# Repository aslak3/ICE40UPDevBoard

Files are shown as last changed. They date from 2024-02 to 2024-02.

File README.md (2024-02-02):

# ICE40UPDevBoard: an iCE40UP5K development board

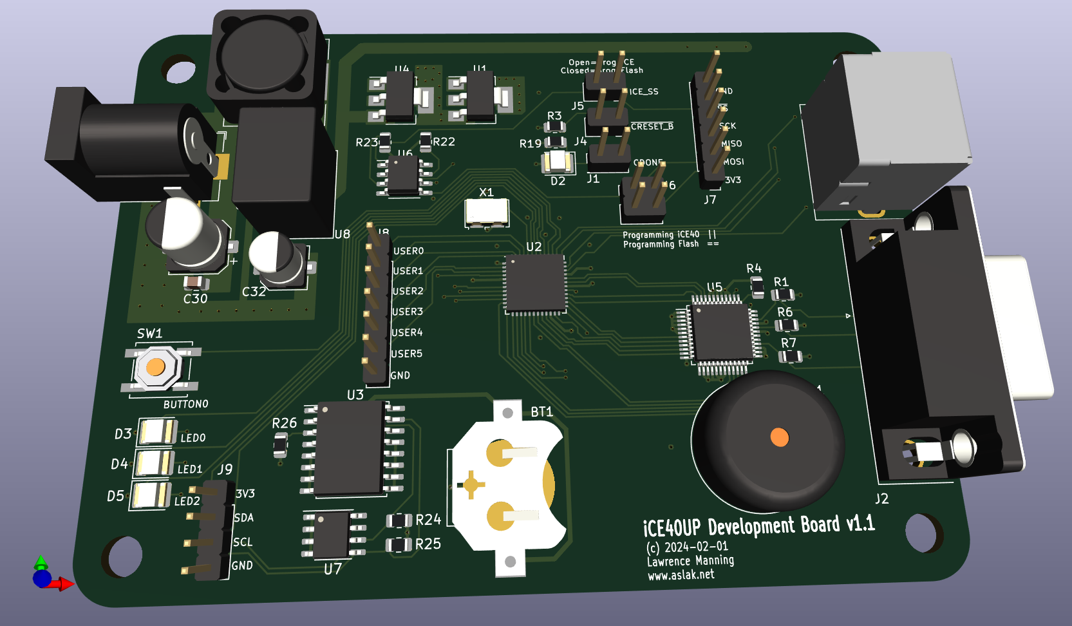
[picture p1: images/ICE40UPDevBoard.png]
ICE40UPDevBoard PCB


## Features

The specification for this development board is as follows:

* [iCE40UP5K](https://www.latticesemi.com/view_document?document_id=51968) in QFN
* [N25Q032A](https://docs.rs-online.com/0866/0900766b80f7f8ab.pdf) 32 Mbit SPI flash
* DB15 VGA port:
  * [ADV7123](https://www.analog.com/media/en/technical-documentation/data-sheets/ADV7123-EP.pdf) RGB DAC
* PS/2 port with two channels for a mouse and keyboard
* I2C:
  * [DS3231M](https://www.analog.com/media/en/technical-documentation/data-sheets/ds3231m.pdf) RTC
  * [AT24C64](https://ww1.microchip.com/downloads/en/devicedoc/doc0336.pdf) EEPROM
  * Header for I2C connections
* 3 LEDs and a button
* User header with 6 available FPGA pins
* Powered by a 5V switching regulator (eg a 5V [PM05S050A](https://filecenter.deltaww.com/products/download/01/0102/datasheet/DS_PM05S.pdf)) and a barrel jack

A [schematic](ICE40UPDevBoard.pdf) is included here, along with the
[KiCAD](https://www.kicad.org) data files, whcih are in  KiCAD 6 format.

## PCB design

The PCB is a 4 layer board.  My boards were manufactured by
[JLCPCB](https://www.jlcpcb.com).

## Using

The jumper mechanism to route the SPI signals which carry the configuration
data from the programmer was borrowed directly from the [Lattice’s iCE40
UltraPlus Breakout
Board](https://www.latticesemi.com/view_document?document_id=51987).

Any iCE40 compatible programmer should be useable.  I built my own, out of a
Pi Pico, which is documented in [another repo](https://github.com/aslak3/spi-flasher).
The programmer has been used to program both the attached flash and the FPGA directly.

## Possible gotchas

The design of this board is a very slightly tweaked version of the build I
have on my bench.  I have tweaked the LED and button connection after
finding out that the three LED pins on the iCE40UP cannot source current for
an LED and must sink it instead.

The following features have not been tested yet:

* I2C bus and peripheral ICs
* PS/2 port

## Blog

The best place to learn about this board is undoubtably [my
blog](https://www.aslak.net/), including this post:

* [Design and build of a Lattice iCE40UP development board](https://www.aslak.net/index.php/2024/01/31/design-and-build-of-a-lattice-ice40up-development-board/)

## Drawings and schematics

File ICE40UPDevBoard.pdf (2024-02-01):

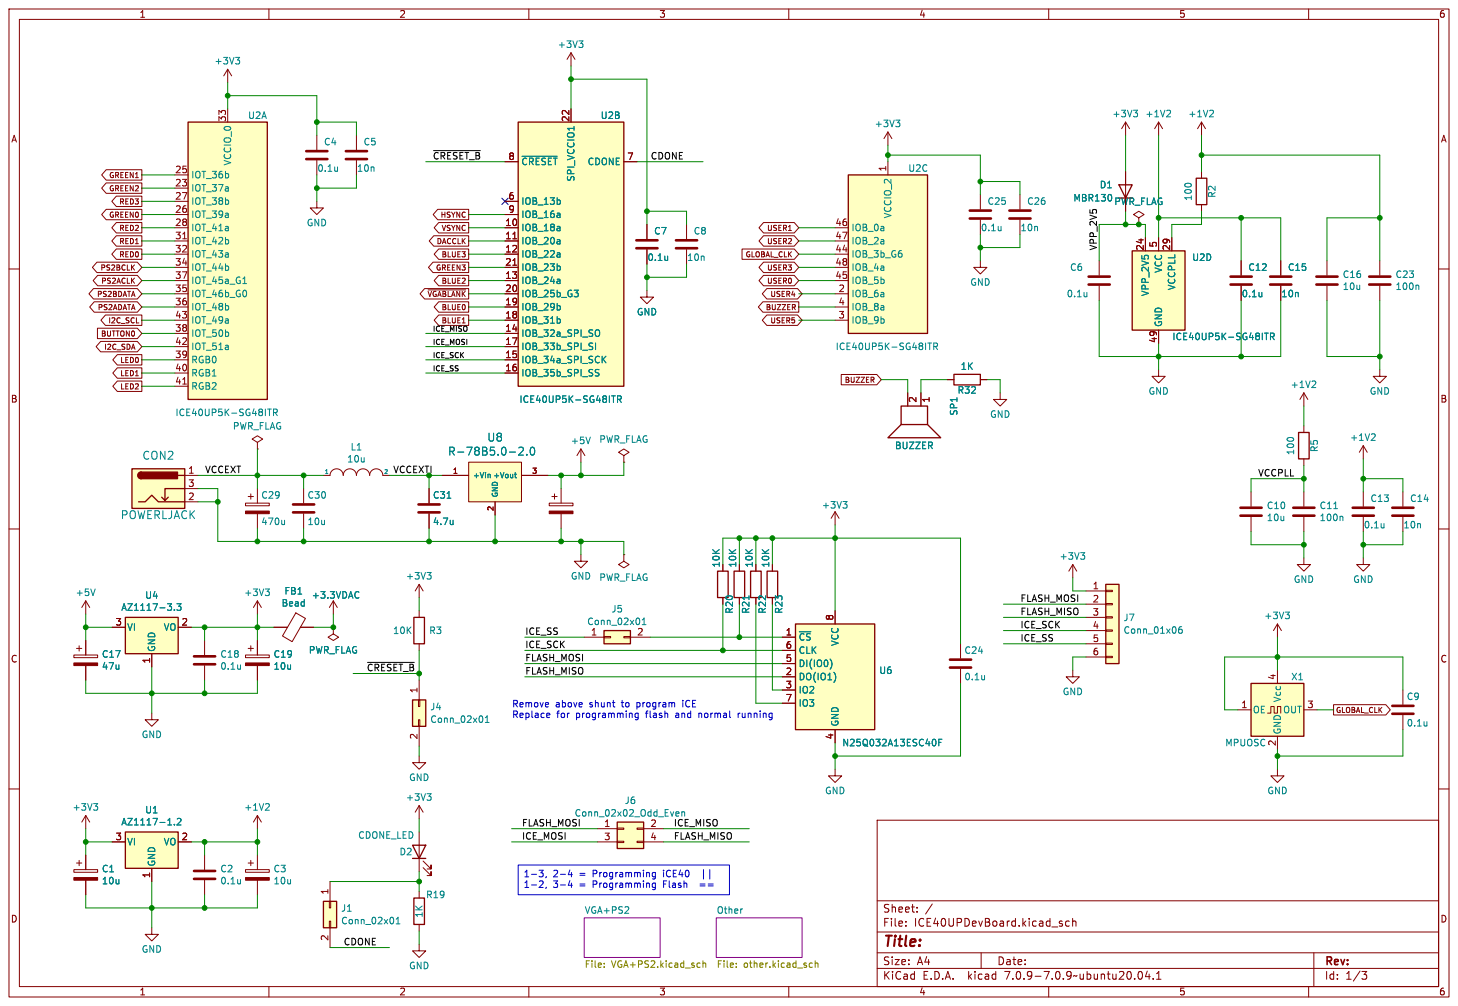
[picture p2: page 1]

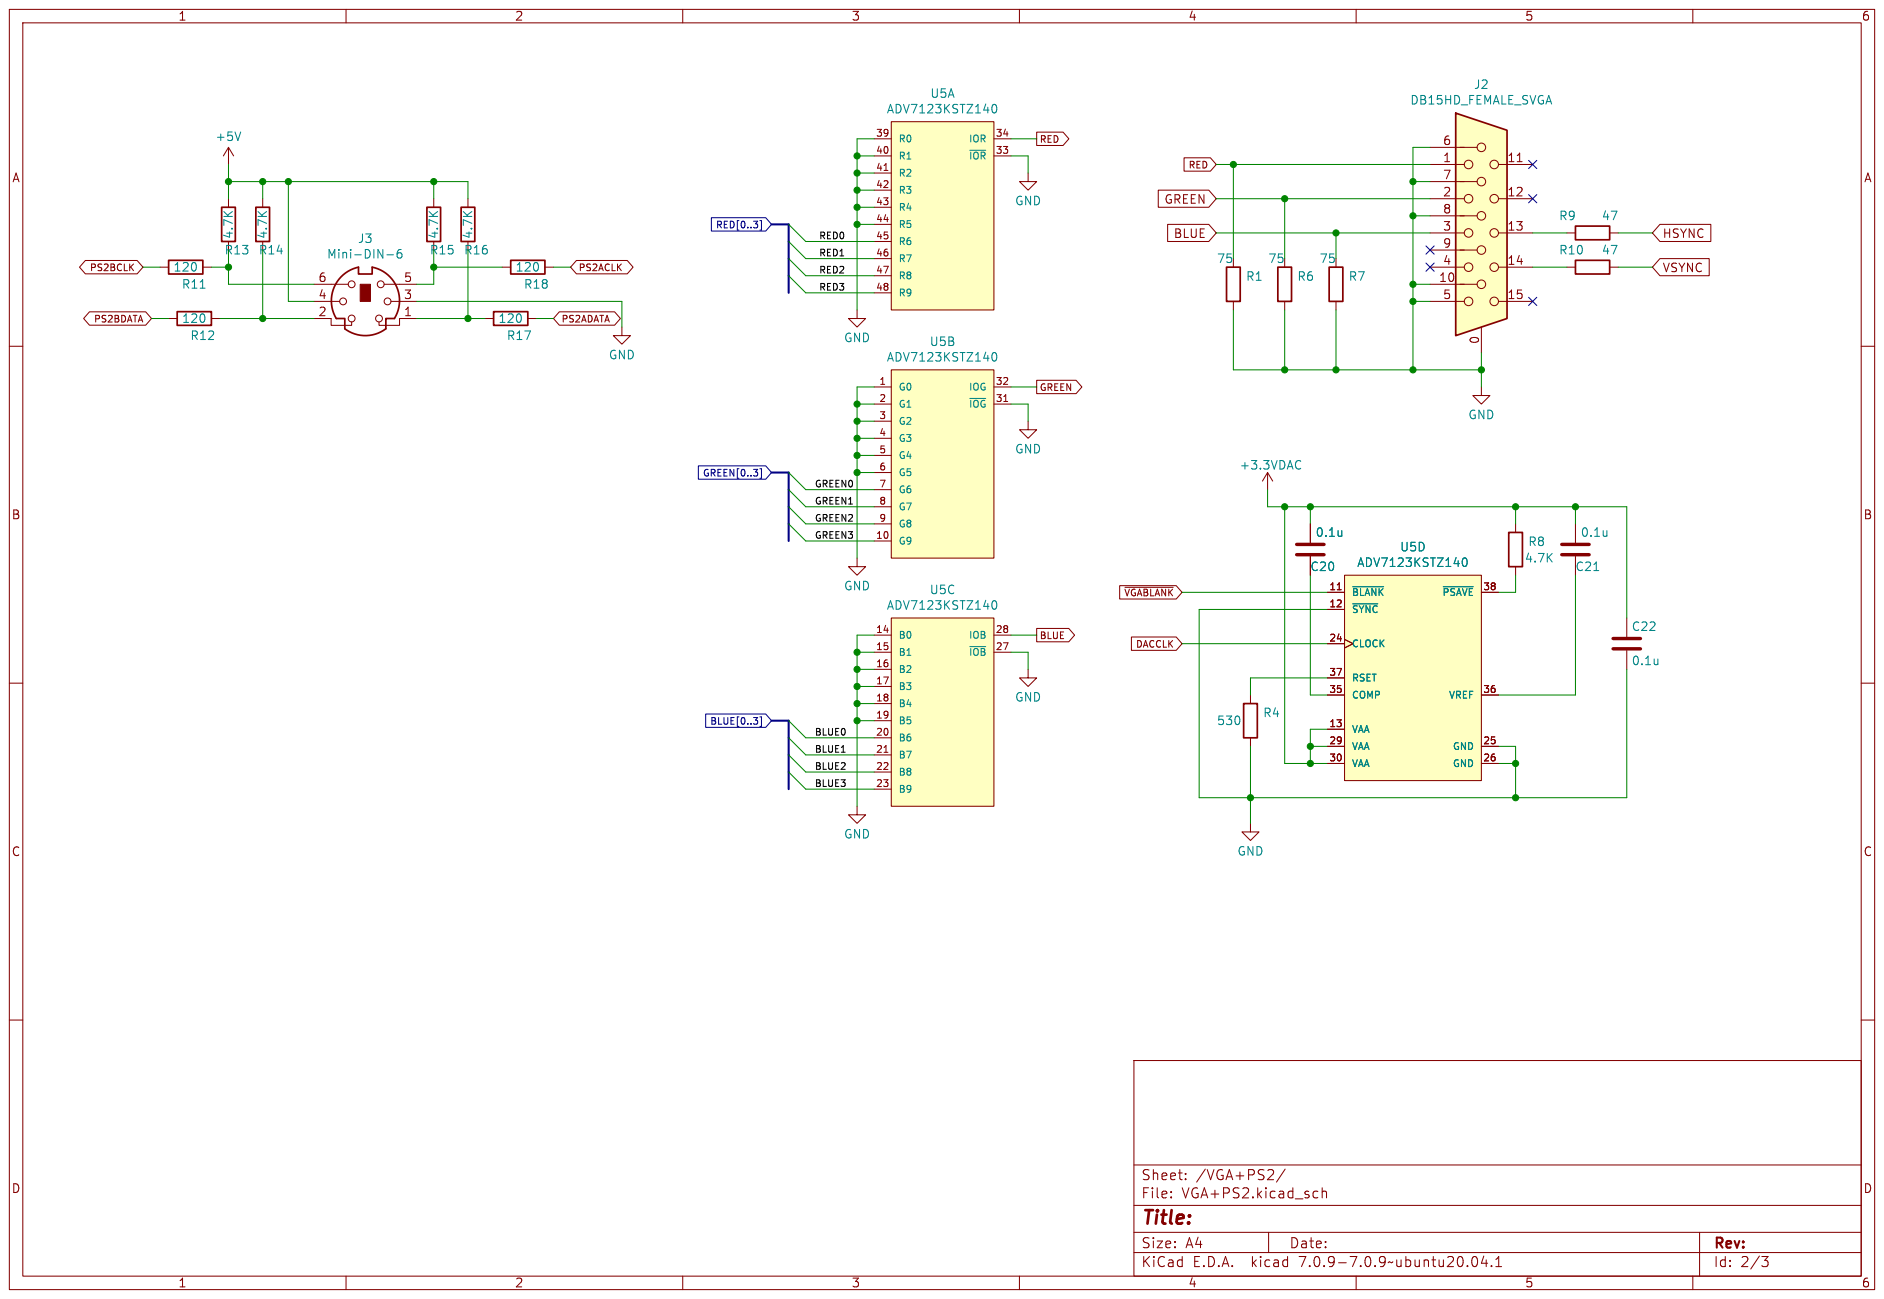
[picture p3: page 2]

Id: 2/3 Title: File: VGA+PS2.kicad_sch Sheet: /VGA+PS2/

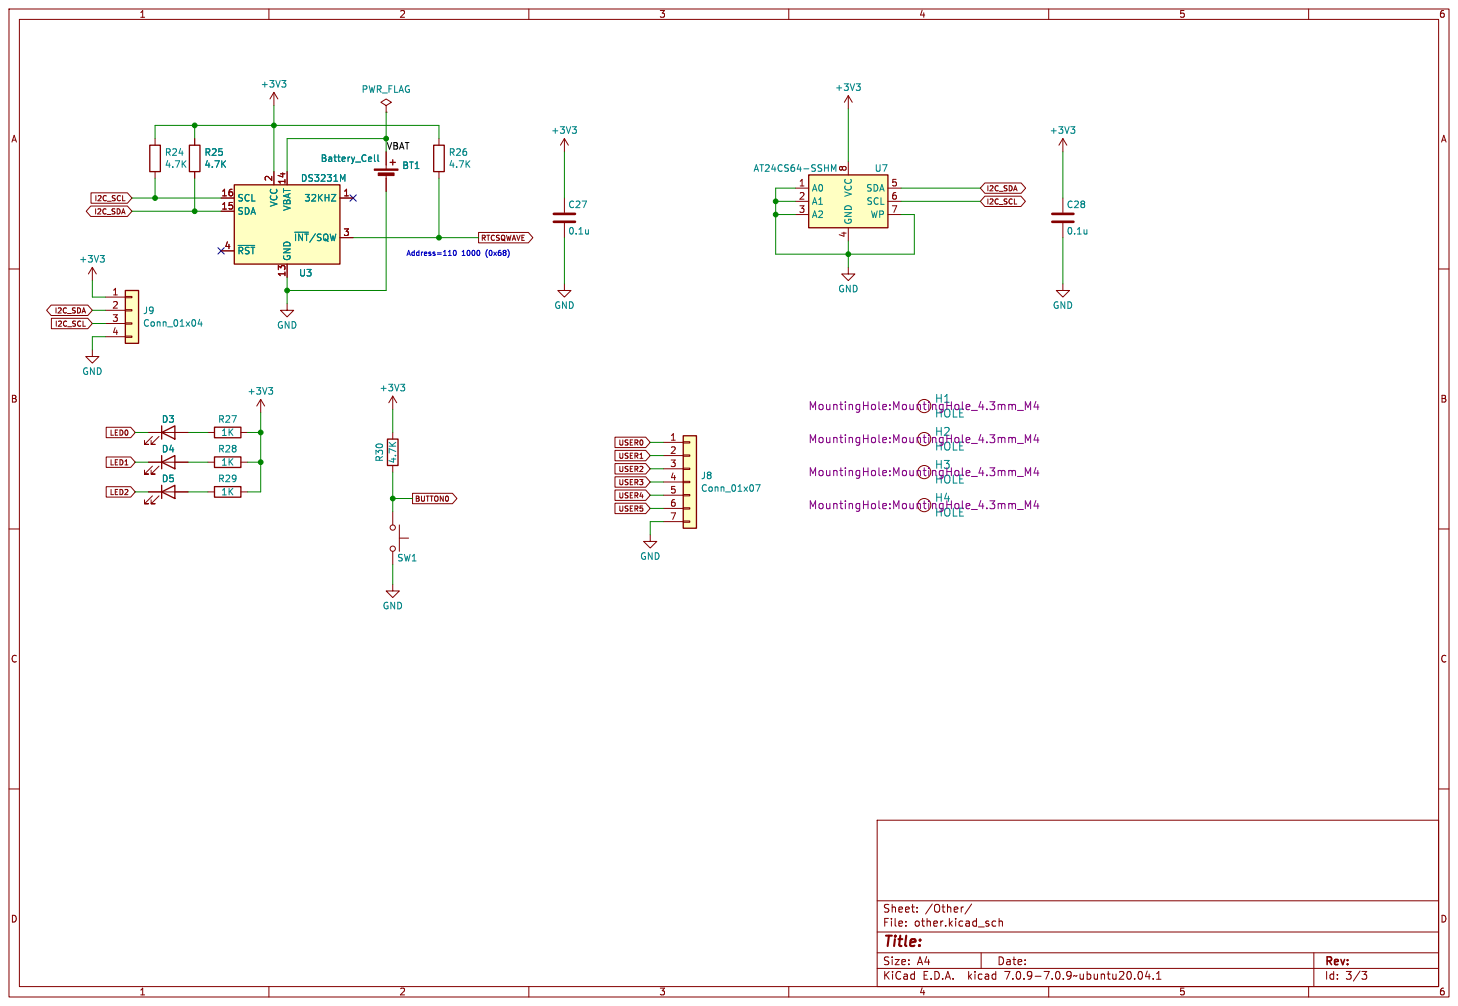
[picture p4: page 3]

4 SDA 5 SCL 6 WP 7 VCC

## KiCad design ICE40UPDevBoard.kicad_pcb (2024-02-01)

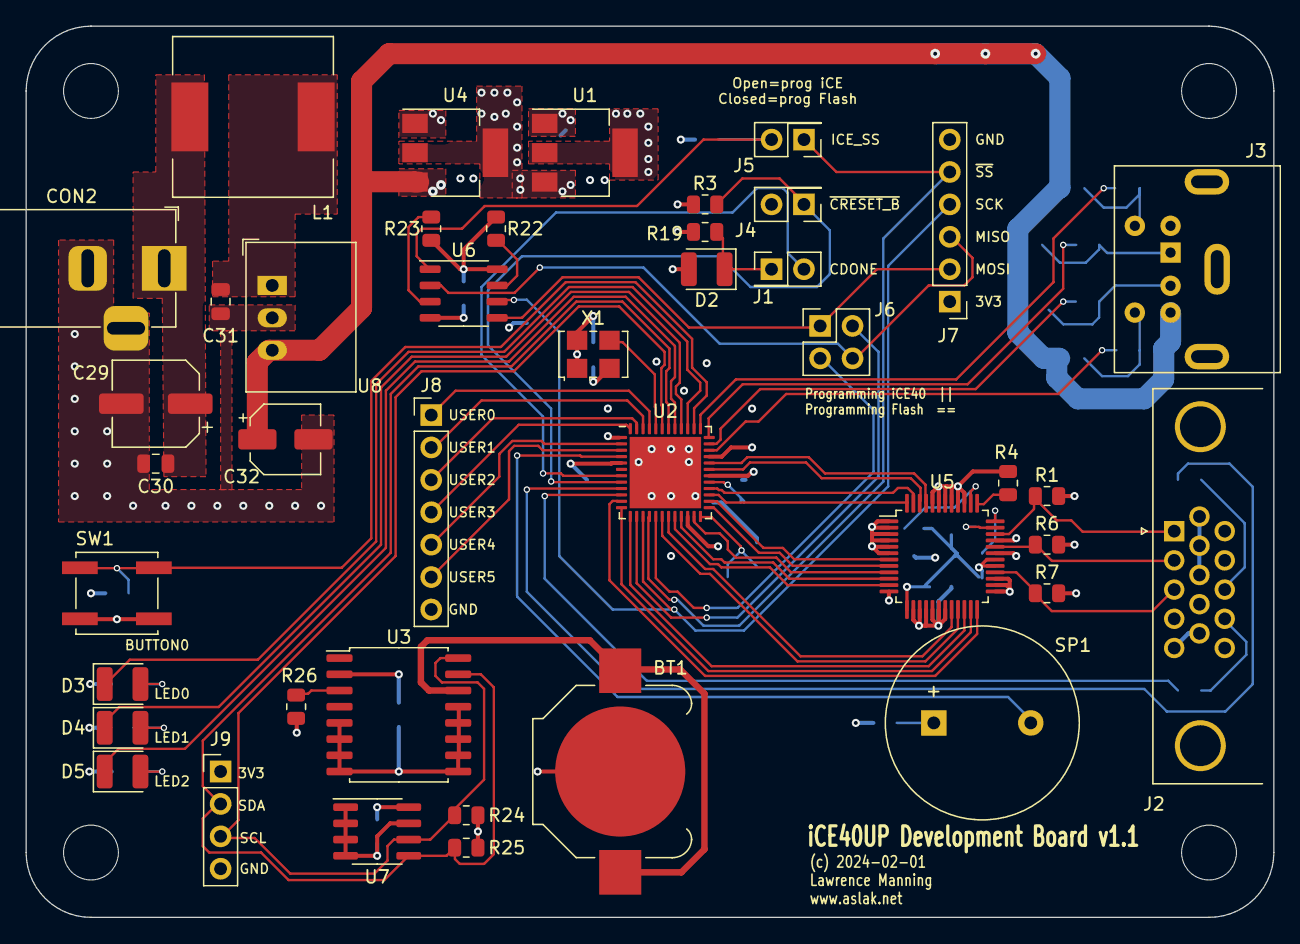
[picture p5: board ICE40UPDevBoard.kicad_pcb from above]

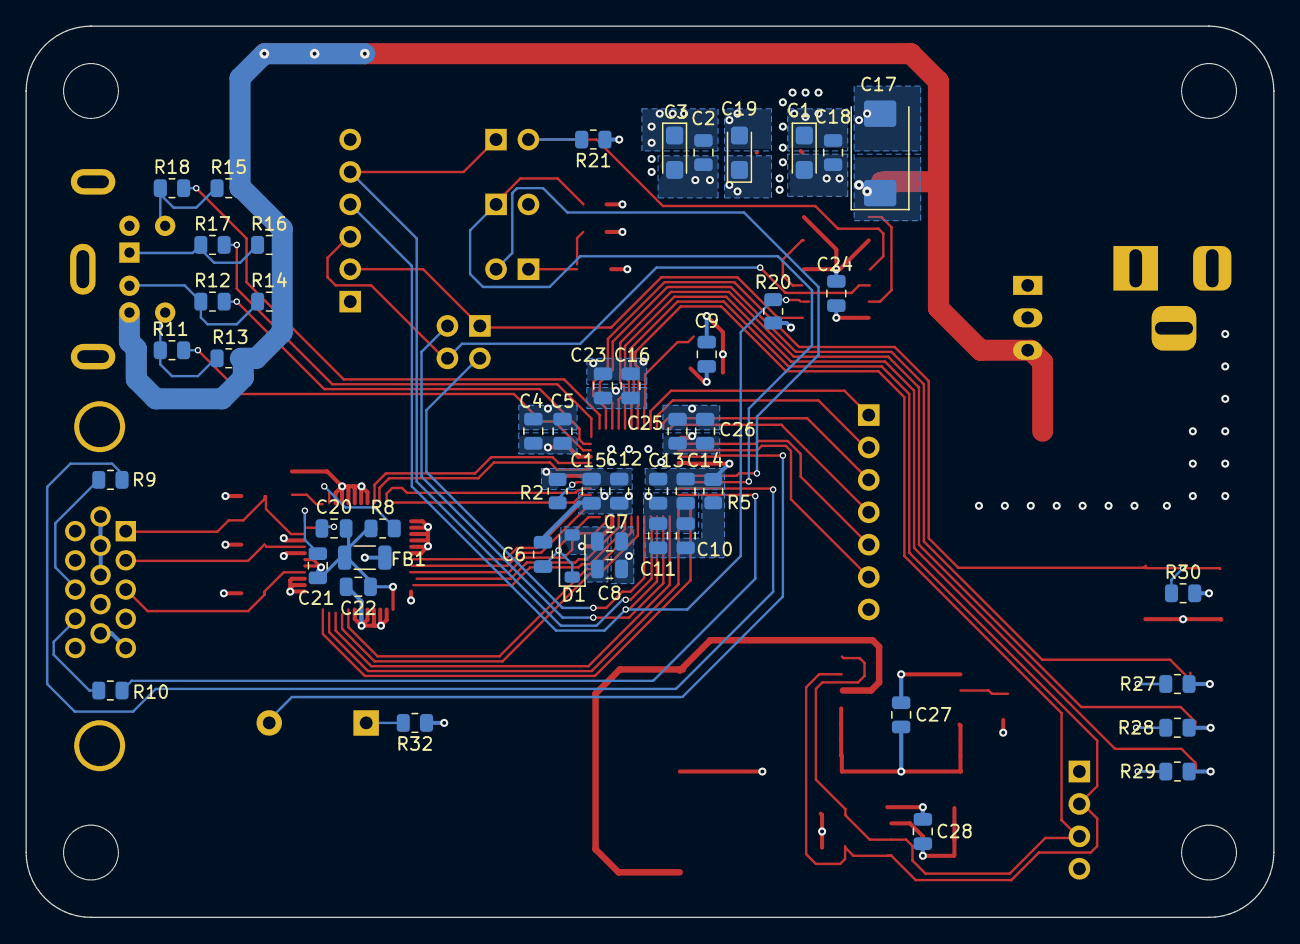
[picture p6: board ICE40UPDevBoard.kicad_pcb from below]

Board: 4 copper layers, 97.8 x 69.8 mm, 96 parts (50 on the bottom side), 75 nets.

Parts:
BT1: Battery_Cell; BatteryHolder_Keystone_3000_1x12mm
C1, C3, C19: 10u; CP_EIA-3216-10_Kemet-I
C2, C4, C6, C7, C9, C12, C13, C18, C20, C21, C22, C24, C25, C27, C28: 0.1u; C_0805_2012Metric
C5, C8, C14, C15, C26: 10n; C_0805_2012Metric
C10, C16, C30: 10u; C_0805_2012Metric
C11, C23: 100n; C_0805_2012Metric
C17: 47u; CP_EIA-7343-15_Kemet-W
C29: 470u; CP_Elec_6.3x7.7
C31: 4.7u; C_0805_2012Metric
C32: 10u; CP_Elec_5x5.7
CON2: POWERLJACK; BarrelJack_Horizontal
D1: MBR130; D_SOD-123
D2, D3, D4, D5: CDONE_LED; LED_1210_3225Metric
FB1: Bead; L_1206_3216Metric
H1, H2, H3, H4: HOLE; MountingHole_4.3mm_M4
J1, J4, J5: Conn_02x01; PinHeader_2x01_P2.54mm_Vertical
J2: DB15HD_FEMALE_SVGA; DSUB-15-HD_Female_Horizontal_P2.29x1.98mm_EdgePinOffset3.03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
J3: Mini-DIN-6; Connector_Mini-DIN_Female_6Pin_2rows
J6: Conn_02x02_Odd_Even; PinHeader_2x02_P2.54mm_Vertical
J7: Conn_01x06; PinHeader_1x06_P2.54mm_Vertical
J8: Conn_01x07; PinHeader_1x07_P2.54mm_Vertical
J9: Conn_01x04; PinHeader_1x04_P2.54mm_Vertical
L1: 10u; L_12x12mm_H4.5mm
R1, R6, R7: 75; R_0805_2012Metric
R2, R5: 100; R_0805_2012Metric
R3, R20, R21, R22, R23: 10K; R_0805_2012Metric
R4: 530; R_0805_2012Metric
R8, R13, R14, R15, R16, R24, R25, R26, R30: 4.7K; R_0805_2012Metric
R9, R10: 47; R_0805_2012Metric
R11, R12, R17, R18: 120; R_0805_2012Metric
R19, R27, R28, R29, R32: 1K; R_0805_2012Metric
SP1: BUZZER; Buzzer_15x7.5RM7.6
SW1: RESETBUTTON; SW_Push_1P1T_NO_CK_KSC6xxJ
U1: AZ1117-1.2; SOT-223-3_TabPin2
U2: ICE40UP5K-SG48ITR; QFN-48-1EP_7x7mm_P0.5mm_EP5.6x5.6mm
U3: DS3231M; SOIC-16W_7.5x10.3mm_P1.27mm
U4: AZ1117-3.3; SOT-223-3_TabPin2
U5: ADV7123KSTZ140; LQFP-48_7x7mm_P0.5mm
U6: N25Q032A13ESC40F; SOP-8_3.9x4.9mm_P1.27mm
U7: AT24CS64-SSHM; SOIC-8_3.9x4.9mm_P1.27mm
U8: R-78B5.0-2.0; Converter_DCDC_RECOM_R-78E-0.5_THT
X1: MPUOSC; Oscillator_SMD_SeikoEpson_SG8002LB-4Pin_5.0x3.2mm

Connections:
+1V2: C2.1, C3.1, C12.1, C13.1, C14.1, C15.1, C16.1, C23.1, R2.1, R5.1, U1.2 (VO), U2.5 (VCC), U2.30 (VCC)
+3.3VDAC: C20.2, C21.2, C22.1, FB1.1, R8.1, U5.13 (VAA), U5.29 (VAA), U5.30 (VAA)
+3V3: C1.1, C4.1, C5.1, C7.1, C8.1, C9.1, C18.1, C19.1, C24.1, C25.1, C26.1, C27.1, C28.1, D1.2 (A), D2.2 (A), FB1.2, J7.1, J9.1, R3.1, R20.1, R21.1, R22.1, R23.1, R24.1, R25.1, R26.1, R27.2, R28.2, R29.2, R30.2, U1.3 (VI), U2.1 (VCCIO_2), U2.22 (SPI_VCCIO1), U2.33 (VCCIO_0), U3.2 (VCC), U4.2 (VO), U6.8 (VCC), U7.8 (VCC), X1.1 (OE), X1.4 (Vcc)
+5V: C17.1, C32.1, J3.4, R13.2, R14.2, R15.2, R16.2, U4.3 (VI), U8.3 (+Vout)
/CDONE: J1.2, U2.7 (CDONE)
/FLASH_MISO: J6.4, J7.3, U6.2 (DO(IO1))
/FLASH_MOSI: J6.1, J7.2, U6.5 (DI(IO0))
/ICE_MISO: J6.2, U2.14 (IOB_32a_SPI_SO)
/ICE_MOSI: J6.3, U2.17 (IOB_33b_SPI_SI)
/ICE_SCK: J7.4, R20.2, U2.15 (IOB_34a_SPI_SCK), U6.6 (CLK)
/ICE_SS: J5.1, J7.5, U2.16 (IOB_35b_SPI_SS)
/Other/VBAT: BT1.1 (+), U3.14 (VBAT)
/VCCEXT: C29.1, C30.1, CON2.1, L1.1
/VCCEXTI: C31.1, L1.2, U8.1 (+Vin)
/VCCPLL: C10.1, C11.1, R5.2
/VPP_2V5: C6.1, D1.1 (K), U2.24 (VPP_2V5)
/~CRESET_B: J4.1, R3.2, U2.8 (~CRESET)
BLUE: J2.3, R7.1, U5.28 (IOB)
BLUE0: U2.19 (IOB_29b), U5.20 (B6)
BLUE1: U2.18 (IOB_31b), U5.21 (B7)
BLUE2: U2.13 (IOB_24a), U5.22 (B8)
BLUE3: U2.12 (IOB_22a), U5.23 (B9)
BUTTON0: R30.1, SW1.1, U2.38 (IOT_50b)
BUZZER: SP1.2, U2.4 (IOB_8a)
DACCLK: U2.11 (IOB_20a), U5.24 (CLOCK)
GLOBAL_CLK: U2.44 (IOB_3b_G6), X1.3 (OUT)
GND: BT1.2 (-), C1.2, C2.2, C3.2, C4.2, C5.2, C6.2, C7.2, C8.2, C9.2, C10.2, C11.2, C12.2, C13.2, C14.2, C15.2, C16.2, C17.2, C18.2, C19.2, C22.2, C23.2, C24.2, C25.2, C26.2, C27.2, C28.2, C29.2, C30.2, C31.2, C32.2, CON2.2, CON2.3, J2.0, J2.5, J2.6, J2.7, J2.8, J2.10, J3.3, J4.2, J7.6, J8.7, J9.4, R1.2, R4.2, R6.2, R7.2, R19.2, R32.1, SW1.2, U1.1 (GND), U2.49 (GND), U3.5 (GND), U3.6 (GND), U3.7 (GND), U3.8 (GND), U3.9 (GND), U3.10 (GND), U3.11 (GND), U3.12 (GND), U3.13 (GND), U4.1 (GND), U5.1 (G0), U5.2 (G1), U5.3 (G2), U5.4 (G3), U5.5 (G4), U5.6 (G5), U5.12 (~SYNC), U5.14 (B0), U5.15 (B1), U5.16 (B2), U5.17 (B3), U5.18 (B4), U5.19 (B5), U5.25 (GND), U5.26 (GND), U5.27 (~IOB), U5.31 (~IOG), U5.33 (~IOR), U5.39 (R0), U5.40 (R1), U5.41 (R2), U5.42 (R3), U5.43 (R4), U5.44 (R5), U6.4 (GND), U7.1 (A0), U7.2 (A1), U7.3 (A2), U7.4 (GND), U7.7 (WP), U8.2 (GND), X1.2 (GND)
GREEN: J2.2, R6.1, U5.32 (IOG)
GREEN0: U2.26 (IOT_39a), U5.7 (G6)
GREEN1: U2.25 (IOT_36b), U5.8 (G7)
GREEN2: U2.23 (IOT_37a), U5.9 (G8)
GREEN3: U2.21 (IOB_23b), U5.10 (G9)
HSYNC: R9.1, U2.9 (IOB_16a)
I2C_SCL: J9.3, R24.2, U2.43 (IOT_49a), U3.16 (SCL), U7.6 (SCL)
I2C_SDA: J9.2, R25.2, U2.42 (IOT_51a), U3.15 (SDA), U7.5 (SDA)
LED0: D3.1 (K), U2.39 (RGB0)
LED1: D4.1 (K), U2.40 (RGB1)
LED2: D5.1 (K), U2.41 (RGB2)
unnamed: D2.1 (K), J1.1, R19.1
unnamed: D3.2 (A), R27.1
unnamed: D4.2 (A), R28.1
unnamed: D5.2 (A), R29.1
unnamed: J2.13, R9.2
unnamed: J2.14, R10.2
unnamed: J3.1, R16.1, R17.1
unnamed: J3.2, R12.2, R14.1
unnamed: J3.5, R15.1, R18.1
unnamed: J3.6, R11.2, R13.1
unnamed: J5.2, R21.2, U6.1 (~CS)
unnamed: R32.2, SP1.1
unnamed: R2.2, U2.29 (VCCPLL)
unnamed: C20.1, U5.35 (COMP)
unnamed: R4.1, U5.37 (RSET)
unnamed: C21.1, U5.36 (VREF)
unnamed: R8.2, U5.38 (~PSAVE)
unnamed: R23.2, U6.3 (IO2)
unnamed: R22.2, U6.7 (IO3)
PS2ACLK: R18.2, U2.37 (IOT_45a_G1)
PS2ADATA: R17.2, U2.36 (IOT_48b)
PS2BCLK: R11.1, U2.34 (IOT_44b)
PS2BDATA: R12.1, U2.35 (IOT_46b_G0)
RED: J2.1, R1.1, U5.34 (IOR)
RED0: U2.32 (IOT_43a), U5.45 (R6)
RED1: U2.31 (IOT_42b), U5.46 (R7)
RED2: U2.28 (IOT_41a), U5.47 (R8)
RED3: U2.27 (IOT_38b), U5.48 (R9)
RTCSQWAVE: R26.2, U3.3 (~INT/SQW)
USER0: J8.1, U2.45 (IOB_5b)
USER1: J8.2, U2.46 (IOB_0a)
USER2: J8.3, U2.47 (IOB_2a)
USER3: J8.4, U2.48 (IOB_4a)
USER4: J8.5, U2.2 (IOB_6a)
USER5: J8.6, U2.3 (IOB_9b)
VSYNC: R10.1, U2.10 (IOB_18a)
~VGABLANK: U2.20 (IOB_25b_G3), U5.11 (~BLANK)

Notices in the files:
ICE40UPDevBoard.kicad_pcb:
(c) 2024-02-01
